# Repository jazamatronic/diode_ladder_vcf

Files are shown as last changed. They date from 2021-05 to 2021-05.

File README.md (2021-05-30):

# diode_ladder_vcf

A Diode Ladder VCF

Å voltage controlled lowpass diode ladder filter.
Cutoff and Res master knobs. Control voltage inputs for both Cutoff and Res, with attenuators.
Selectable resonance gain compensation mode so the volume stays relatively flat as resonance increases.
Selectable keyboard tracking mode and it self oscillates, so the filter can be played.
Has a soft-clipping overdrive circuit on the front-end, plus adjustable input attenuation.
Has a HP-like mode that works by subtracting the LP signal from the input - there's a front-panel pot to help tune this.

Tiny demo and snapshots here:

https://imgur.com/a/kTCuVp1

Inspiration taken from:
http://www.timstinchcombe.co.uk/index.php?pge=diode

https://www.instructables.com/Diode-Ladder-VCF-With-NO-PCB/

https://www.haraldswerk.de/Filter/NGF_Ladder/NGF_Ladder.html

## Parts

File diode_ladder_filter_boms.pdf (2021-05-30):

Feuille1

# diode_ladder_filter_fp

Sat May 29 14:07:22 2021
Eeschema 5.1.5+dfsg1-2build2
Component Count:16
Ref | Value | Description
J1 | IN | Audio Jack, 2 Poles (Mono / TS), Switched T Pole (Normalling)
J2 | V_FC | Audio Jack, 2 Poles (Mono / TS), Switched T Pole (Normalling)
J3 | CON_TOP | Generic connector, single row, 01x10, script generated
J4 | OUT_LP | Audio Jack, 2 Poles (Mono / TS), Switched T Pole (Normalling)
J5 | V_RES | Audio Jack, 2 Poles (Mono / TS), Switched T Pole (Normalling)
J6 | OUT_HP | Audio Jack, 2 Poles (Mono / TS), Switched T Pole (Normalling)
J7 | CON_BTM | Generic connector, single row, 01x08, script generated
RV1, RV4 | 100k | Potentiometer
RV2, RV3, RV5, RV6, RV7 | 100k | Potentiometer
SW1, SW2 | SW_SPDT | Switch, single pole double throw

Feuille1

# diode_ladder_filter_bp

Sat May 29 14:15:08 2021
Eeschema 5.1.5+dfsg1-2build2
Component Count:77
Ref | Value | Description
C1, C2, C3, C4, C5, C6 | 0.1u | Polarized capacitor, small symbol
C7, C8 | 22p | Unpolarized capacitor, small symbol
C9, C15 | 10u | Unpolarized capacitor, small symbol
C10 | 220u | Unpolarized capacitor, small symbol
C11, C12, C13, C14 | 100n | Unpolarized capacitor, small symbol
D1, D2, D3, D4, D5, D6, D7, D8, D9, D10, D11, D12 | 1N4148 | Diode, small symbol, filled shape
D13, D14 | 1N5817 | 20V 1A Schottky Barrier Rectifier Diode, DO-41
J3 | CON_TOP | Generic connector, single row, 01x10
J5 | PWR_HDR | Generic connector, double row, 02x08, odd/even pin numbering scheme (row 1 odd numbers, row 2 even numbers)
J7 | CON_BTM | Generic connector, single row, 01x08
Q1, Q2 | PMP4201Y,135
Q3, Q4 | BC557 | 0.1A Ic, 45V Vce, PNP Small Signal Transistor, TO-92
R1, R2, R25, R33 | 2k2 | Resistor, small symbol
R3, R4, R38 | 100k | Resistor, small symbol
R5 | 2k | Resistor, small symbol
R6 | 900 | Resistor, small symbol
R7 | 100 | Resistor, small symbol
R8, R12, R18, R19, R20, R22, R28, R29, R34, R35 | 10k | Resistor, small symbol
R9, R16, R23, R26 | 470 | Resistor, small symbol
R10 | 4k7 | Resistor, small symbol
R11 | 1M2 | Resistor, small symbol
R13, R14, R17, R32 | 1k | Resistor, small symbol
R15 | 7k5 | Resistor, small symbol
R21 | 75k | Resistor, small symbol
R24 | 47k | Resistor, small symbol
R27, R30 | 22k | Resistor, small symbol
R31 | 470k | Resistor, small symbol
R36, R37 | 220k | Resistor, small symbol
U1 | LM13700 | Dual Operational Transconductance Amplifiers DIP-16
U2, U3 | TL074 | Quad Low-Noise JFET-Input Operational Amplifiers, DIP-14

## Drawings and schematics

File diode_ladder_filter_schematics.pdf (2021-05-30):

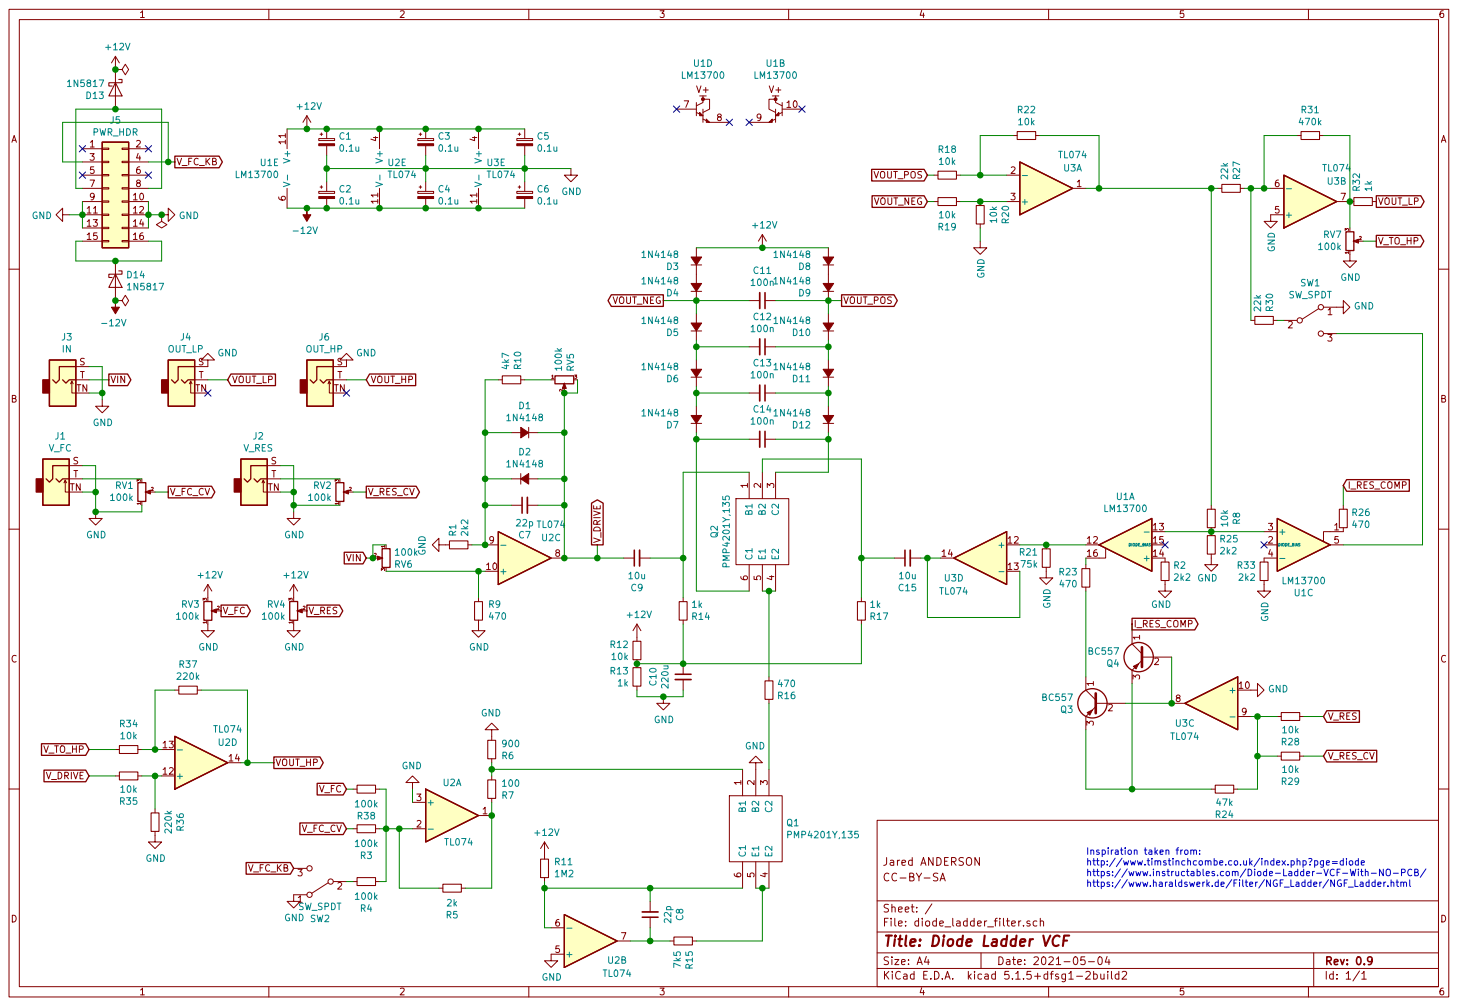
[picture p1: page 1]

11 | 12
13 | 14

Jared ANDERSON
File: diode_ladder_filter.sch Sheet: / CC-BY-SA

Inspiration taken from:
http://www.timstinchcombe.co.uk/index.php?pge=diode
https://www.instructables.com/Diode-Ladder-VCF-With-NO-PCB/
https://www.haraldswerk.de/Filter/NGF_Ladder/NGF_Ladder.html

Id: 1/1 Title: Diode Ladder VCF

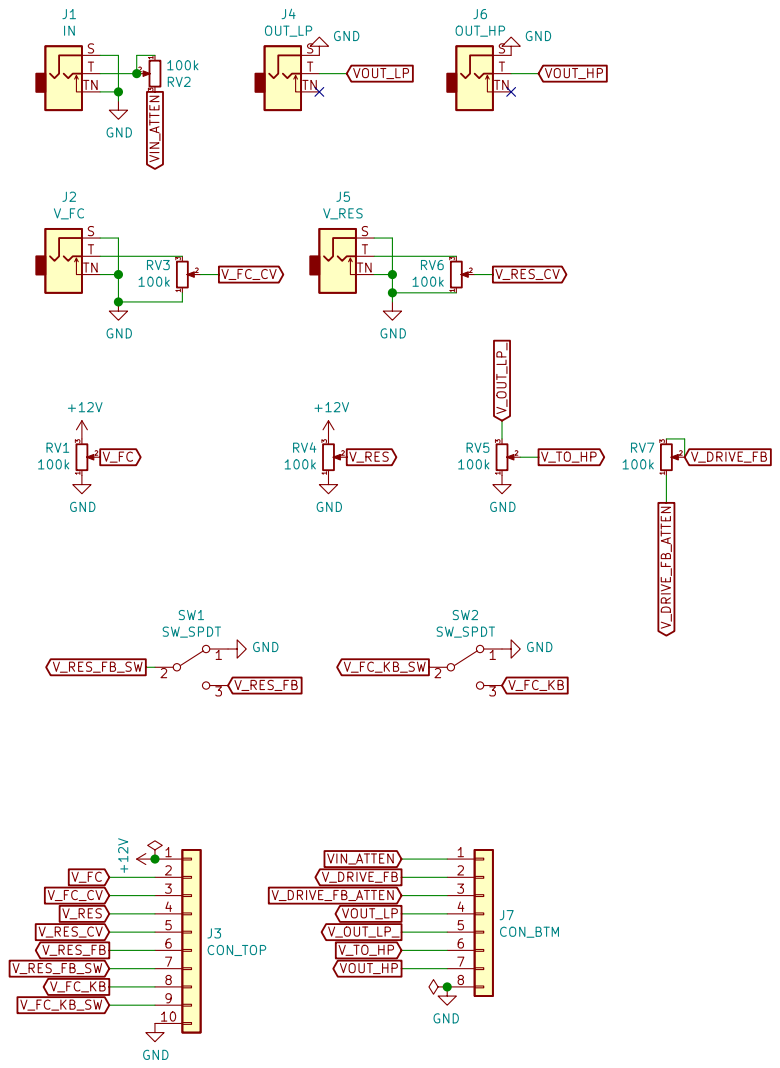
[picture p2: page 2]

File: diode_ladder_filter_fp.sch Sheet: / CC-BY-SA

Id: 1/1 Title: Diode Ladder VCF Front Panel

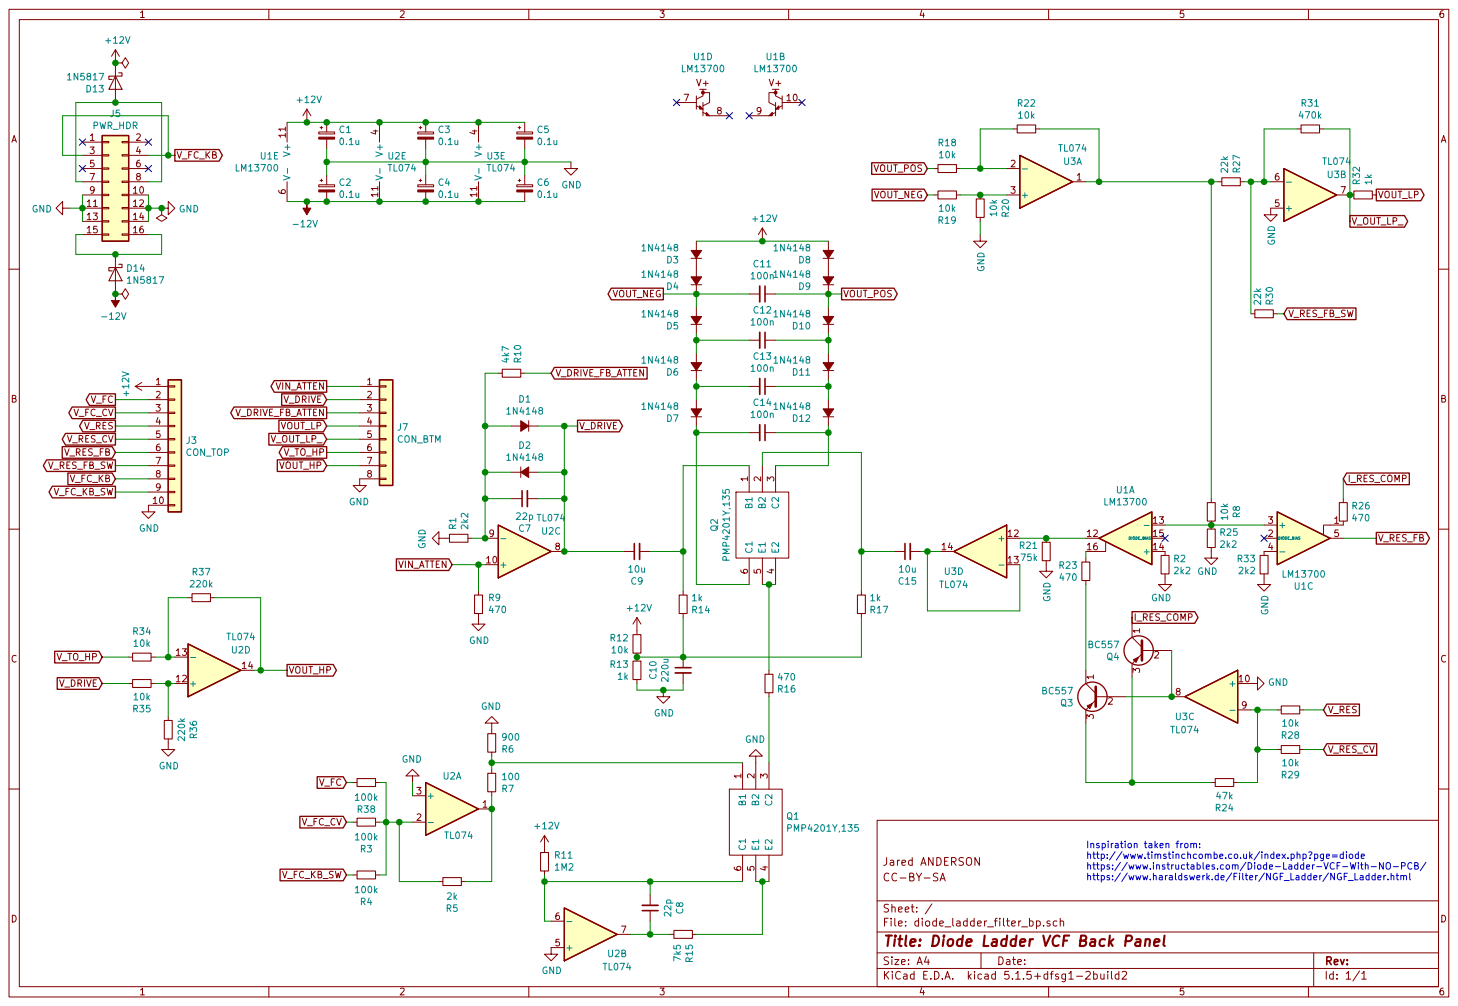
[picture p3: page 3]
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

Jared ANDERSON
File: diode_ladder_filter_bp.sch Sheet: / CC-BY-SA

Id: 1/1 Title: Diode Ladder VCF Back Panel

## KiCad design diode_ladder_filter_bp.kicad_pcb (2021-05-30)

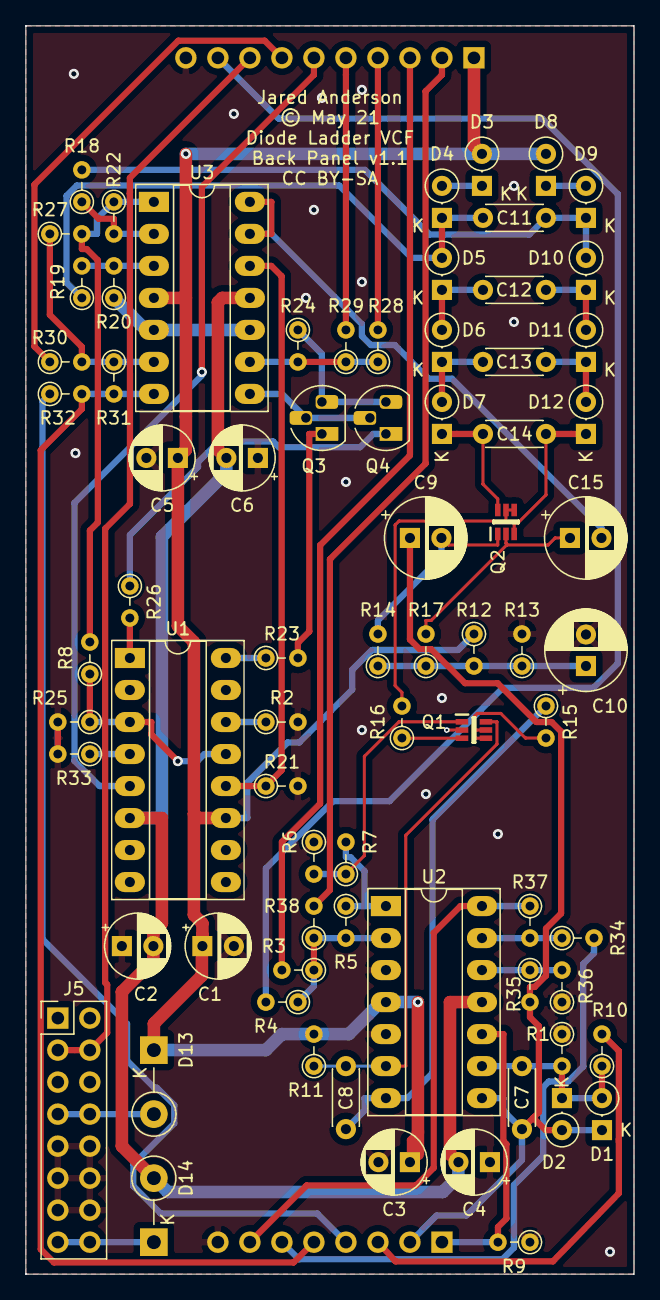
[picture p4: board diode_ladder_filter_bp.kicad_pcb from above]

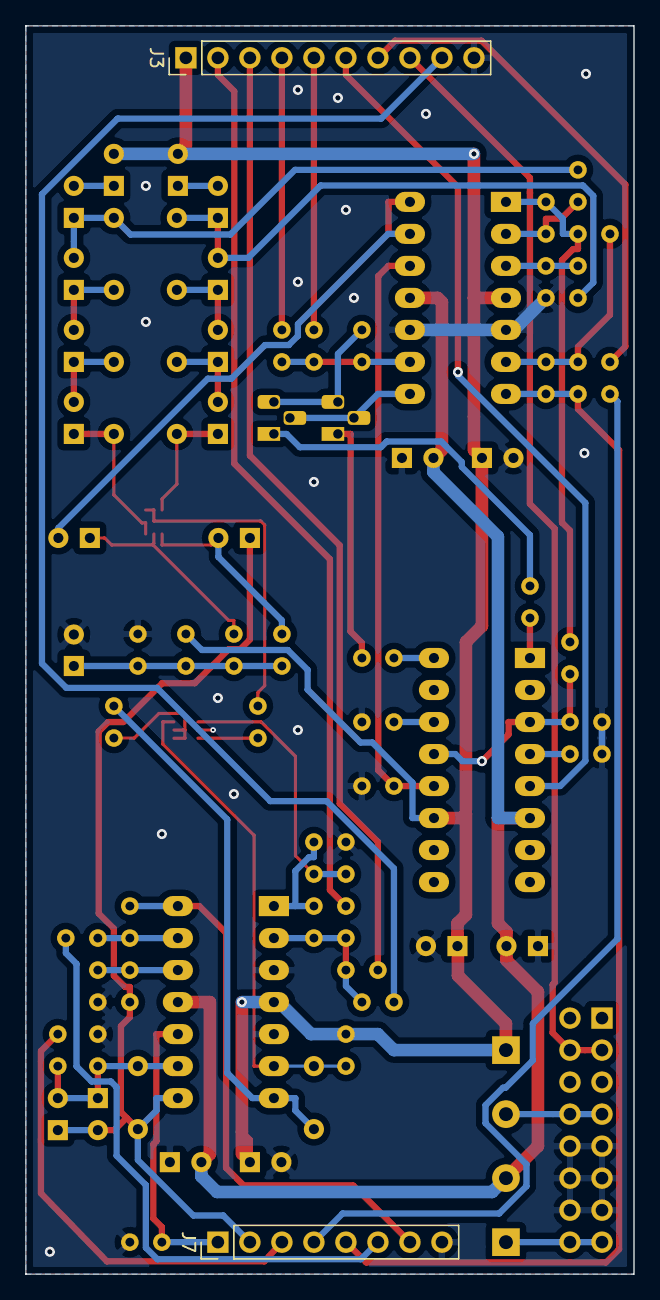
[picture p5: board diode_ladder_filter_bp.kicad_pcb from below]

Board: 2 copper layers, 48.3 x 99.1 mm, 77 parts (2 on the bottom side), 60 nets.

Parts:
C1, C2, C3, C4, C5, C6: 0.1u; CP_Radial_D5.0mm_P2.50mm
C7, C8: 22p; C_Disc_D4.3mm_W1.9mm_P5.00mm
C9, C15: 10u; CP_Radial_D6.3mm_P2.50mm
C10: 220u; CP_Radial_D6.3mm_P2.50mm
C11, C12, C13, C14: 100n; C_Disc_D4.3mm_W1.9mm_P5.00mm
D1, D2, D3, D4, D5, D6, D7, D8, D9, D10, D11, D12: 1N4148; D_DO-35_SOD27_P2.54mm_Vertical_KathodeUp
D13, D14: 1N5817; D_DO-41_SOD81_P5.08mm_Vertical_KathodeUp
J3: CON_TOP; PinHeader_1x10_P2.54mm_Vertical
J5: PWR_HDR; PinHeader_2x08_P2.54mm_Vertical
J7: CON_BTM; PinHeader_1x08_P2.54mm_Vertical
Q1, Q2: PMP4201Y,135; SOT65P210X110-6N
Q3, Q4: BC557; TO-92_HandSolder
R1, R2, R25, R33: 2k2; R_Axial_DIN0204_L3.6mm_D1.6mm_P2.54mm_Vertical
R3, R4, R38: 100k; R_Axial_DIN0204_L3.6mm_D1.6mm_P2.54mm_Vertical
R5: 2k; R_Axial_DIN0204_L3.6mm_D1.6mm_P2.54mm_Vertical
R6: 900; R_Axial_DIN0204_L3.6mm_D1.6mm_P2.54mm_Vertical
R7: 100; R_Axial_DIN0204_L3.6mm_D1.6mm_P2.54mm_Vertical
R8, R12, R18, R19, R20, R22, R28, R29, R34, R35: 10k; R_Axial_DIN0204_L3.6mm_D1.6mm_P2.54mm_Vertical
R9, R16, R23, R26: 470; R_Axial_DIN0204_L3.6mm_D1.6mm_P2.54mm_Vertical
R10: 4k7; R_Axial_DIN0204_L3.6mm_D1.6mm_P2.54mm_Vertical
R11: 1M2; R_Axial_DIN0204_L3.6mm_D1.6mm_P2.54mm_Vertical
R13, R14, R17, R32: 1k; R_Axial_DIN0204_L3.6mm_D1.6mm_P2.54mm_Vertical
R15: 7k5; R_Axial_DIN0204_L3.6mm_D1.6mm_P2.54mm_Vertical
R21: 75k; R_Axial_DIN0204_L3.6mm_D1.6mm_P2.54mm_Vertical
R24: 47k; R_Axial_DIN0204_L3.6mm_D1.6mm_P2.54mm_Vertical
R27, R30: 22k; R_Axial_DIN0204_L3.6mm_D1.6mm_P2.54mm_Vertical
R31: 470k; R_Axial_DIN0204_L3.6mm_D1.6mm_P2.54mm_Vertical
R36, R37: 220k; R_Axial_DIN0204_L3.6mm_D1.6mm_P2.54mm_Vertical
U1: LM13700; DIP-16_W7.62mm_Socket_LongPads
U2, U3: TL074; DIP-14_W7.62mm_Socket_LongPads

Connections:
+12V: C1.1, C3.1, C5.1, D3.2, D8.2, D13.1, J3.1, R11.2, R12.1, U1.11, U2.4, U3.4
-12V: C2.2, C4.2, C6.2, D14.2, U1.6, U2.11, U3.11
GND: C1.2, C2.1, C3.2, C4.1, C5.2, C6.1, C10.2, J3.10, J5.9, J5.10, J5.11, J5.12, J5.13, J5.14, J7.8, Q1.2, R1.1, R2.2, R6.1, R9.1, R13.2, R20.1, R21.2, R25.2, R33.2, R36.1, U2.3, U2.5, U3.5, U3.10
I_RES_COMP: Q4.1, R26.1
unnamed: C7.1, D1.2, D2.1, R1.2, R10.1, U2.9
unnamed: C8.1, R15.1, U2.7
unnamed: C8.2, Q1.6, R11.1, U2.6
unnamed: C9.2, Q2.1, R14.2
unnamed: C10.1, R12.2, R13.1, R14.1, R17.1
unnamed: C12.1, D10.1, D11.2
unnamed: C12.2, D5.1, D6.2
unnamed: C13.1, D11.1, D12.2
unnamed: C13.2, D6.1, D7.2
unnamed: C14.1, D12.1, Q2.3
unnamed: C14.2, D7.1, Q2.6
unnamed: C15.1, Q2.2, R17.2
unnamed: C15.2, U3.13, U3.14
unnamed: D3.1, D4.2
unnamed: D8.1, D9.2
unnamed: D13.2, J5.7, J5.8
unnamed: D14.1, J5.15, J5.16
unnamed: Q1.1, R6.2, R7.1
unnamed: Q1.3, R16.1
unnamed: Q1.4, Q1.5, R15.2
unnamed: Q2.4, Q2.5, R16.2
unnamed: Q3.1, R23.2
unnamed: Q3.2, Q4.2, U3.8
unnamed: Q3.3, Q4.3, R24.1
unnamed: R2.1, U1.14
unnamed: R3.1, R4.1, R5.2, R38.1, U2.2
unnamed: R5.1, R7.2, U2.1
unnamed: R18.1, R22.2, U3.2
unnamed: R19.2, R20.2, U3.3
unnamed: R21.1, U1.12, U3.12
unnamed: R8.2, R22.1, R27.2, U3.1
unnamed: R23.1, U1.16
unnamed: R24.2, R28.1, R29.1, U3.9
unnamed: R8.1, R25.1, U1.3, U1.13
unnamed: R26.2, U1.1
unnamed: R27.1, R30.2, R31.1, U3.6
unnamed: R33.1, U1.4
unnamed: R34.1, R37.2, U2.13
unnamed: R35.1, R36.2, U2.12
VIN_ATTEN: J7.1, R9.2, U2.10
VOUT_HP: J7.7, R37.1, U2.14
VOUT_LP: J7.4, R32.1
VOUT_NEG: C11.2, D4.1, D5.2, R19.1
VOUT_POS: C11.1, D9.1, D10.2, R18.2
V_DRIVE: C7.2, C9.1, D1.1, D2.2, J7.2, R35.2, U2.8
V_DRIVE_FB_ATTEN: J7.3, R10.2
V_FC: J3.2, R38.2
V_FC_CV: J3.3, R3.2
V_FC_KB: J3.8, J5.3, J5.4
V_FC_KB_SW: J3.9, R4.2
V_OUT_LP_: J7.5, R31.2, R32.2, U3.7
V_RES: J3.4, R28.2
V_RES_CV: J3.5, R29.2
V_RES_FB: J3.6, U1.5
V_RES_FB_SW: J3.7, R30.1
V_TO_HP: J7.6, R34.2

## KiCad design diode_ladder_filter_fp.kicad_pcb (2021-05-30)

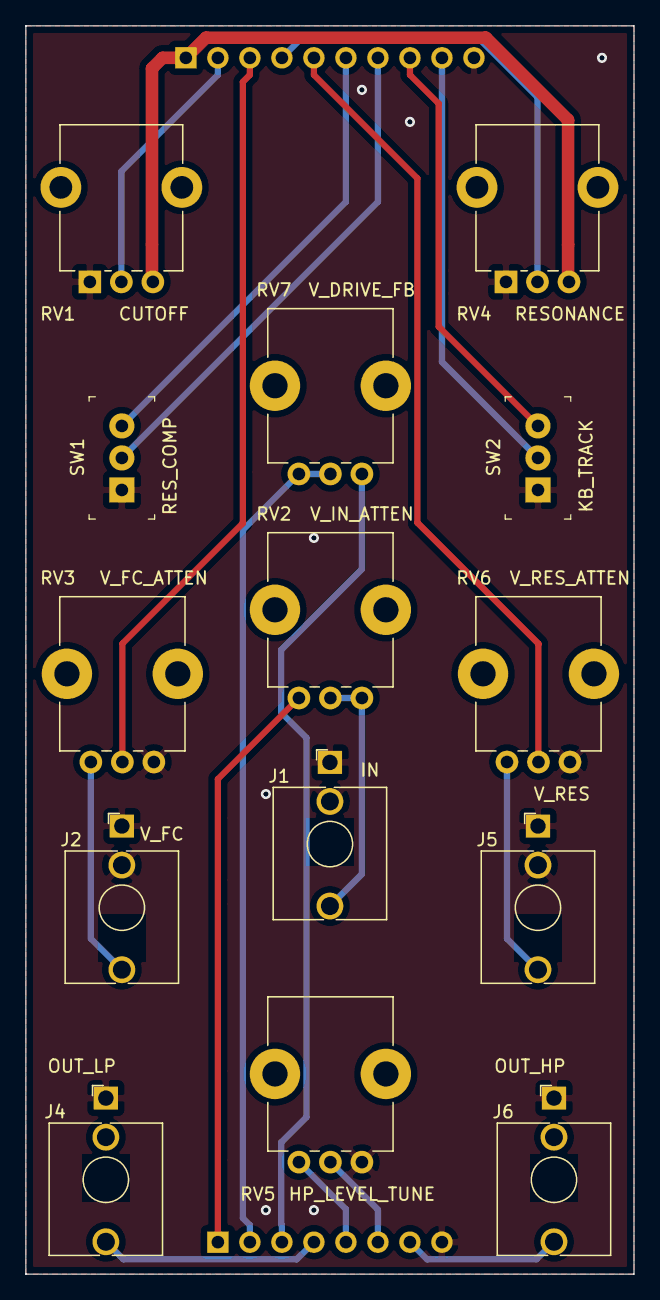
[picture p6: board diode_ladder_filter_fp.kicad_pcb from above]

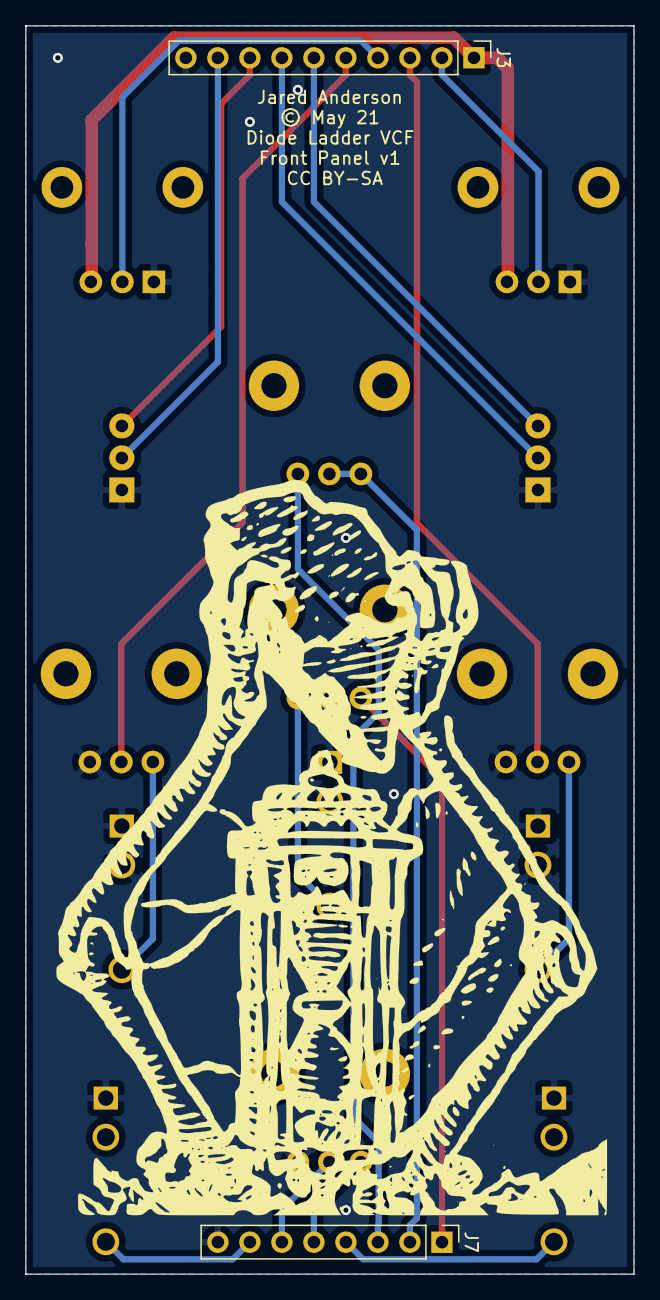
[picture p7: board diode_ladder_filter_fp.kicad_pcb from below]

Board: 2 copper layers, 48.3 x 99.1 mm, 16 parts (2 on the bottom side), 20 nets.

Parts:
J1: IN; Jack_3.5mm_QingPu_WQP-PJ398SM_Vertical_CircularHoles
J2: V_FC; Jack_3.5mm_QingPu_WQP-PJ398SM_Vertical_CircularHoles
J3: CON_TOP; PinHeader_1x10_P2.54mm_Vertical
J4: OUT_LP; Jack_3.5mm_QingPu_WQP-PJ398SM_Vertical_CircularHoles
J5: V_RES; Jack_3.5mm_QingPu_WQP-PJ398SM_Vertical_CircularHoles
J6: OUT_HP; Jack_3.5mm_QingPu_WQP-PJ398SM_Vertical_CircularHoles
J7: CON_BTM; PinHeader_1x08_P2.54mm_Vertical
RV1, RV4: 100k; Potentiometer_Alpha_RD901F-40-00D_Single_Vertical_CircularH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
RV2, RV3, RV5, RV6, RV7: 100k; Potentiometer_Bourns_PTV09A-1_Single_Vertical
SW1, SW2: SW_SPDT; Switch_Toggle_ATE1D-2M3-10-Z

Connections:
+12V: J3.1, RV1.3, RV4.3
GND: J1.S, J1.TN, J2.S, J2.TN, J3.10, J4.S, J5.S, J5.TN, J6.S, J7.8, RV1.1, RV3.1, RV4.1, RV5.1, RV6.1, SW1.1, SW2.1
unnamed: J1.T, RV2.1, RV2.2
unnamed: J2.T, RV3.3
unnamed: J5.T, RV6.3
VIN_ATTEN: J7.1, RV2.3
VOUT_HP: J6.T, J7.7
VOUT_LP: J4.T, J7.4
V_DRIVE_FB: J7.2, RV7.2, RV7.3
V_DRIVE_FB_ATTEN: J7.3, RV7.1
V_FC: J3.2, RV1.2
V_FC_CV: J3.3, RV3.2
V_FC_KB: J3.8, SW2.3
V_FC_KB_SW: J3.9, SW2.2
V_OUT_LP_: J7.5, RV5.3
V_RES: J3.4, RV4.2
V_RES_CV: J3.5, RV6.2
V_RES_FB: J3.6, SW1.3
V_RES_FB_SW: J3.7, SW1.2
V_TO_HP: J7.6, RV5.2

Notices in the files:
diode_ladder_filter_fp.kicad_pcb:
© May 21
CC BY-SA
